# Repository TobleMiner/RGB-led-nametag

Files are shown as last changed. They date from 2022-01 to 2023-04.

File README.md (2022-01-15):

RGB LED nametag
===============

While there are a few commercially available LED nametags out there they
are usually either monochrome only or far too big and bulky to wear.  
This project aims at designing a device solving that problem.  
At only 84mm wide and 29mm tall it is hardly any larger than normal,
boring paper nametags and packs a whole lot more features:

- WLAN enabled
- 48x16 glorious RGB led pixels with more than 16 million colors each
- Powerful ARM Cortex M7 and Xtensa 32bit dual core
- 3MB of onboard data storage

Nyan cat animation playing on the nametag

# Principle of operation

The RGB LEDs on this nametag are common anode LEDs. The LEDs are divided
into groups of 16 columns each. The display is then multiplexed over those
16 columns, always driving one of the 16 columns in each of the three
groups simultaneously. Each of the 3 groups features 48 low side row
drivers driving the R, G and B emitter of all 16 LEDs in the currently
selected column.  
Both the low and high side drivers are designed as shift registers. The
low side drivers are fed with data from a regular SPI while the high side
drivers are connected to a QSPI interface. On the QSPI interface three
of the four data lines are utilized to provide data for all three LED
groups simultaneously.  
Both the SPI and QSPI are peripherals of an STM32F722 MCU. The STM32
takes care of LED multiplexing, power management, user io and USB.  
To provide WLAN connectivity an ESP32 is connected to the STM32 via
an IRQ line, a SPI interface, an I2C interface and a UART. IO0 and EN of
the ESP32 are also connected to the STM32. This allows the STM32 to be
used as a USB to UART bridge allowing normal programming of the ESP32
directly from your favourite IDE.

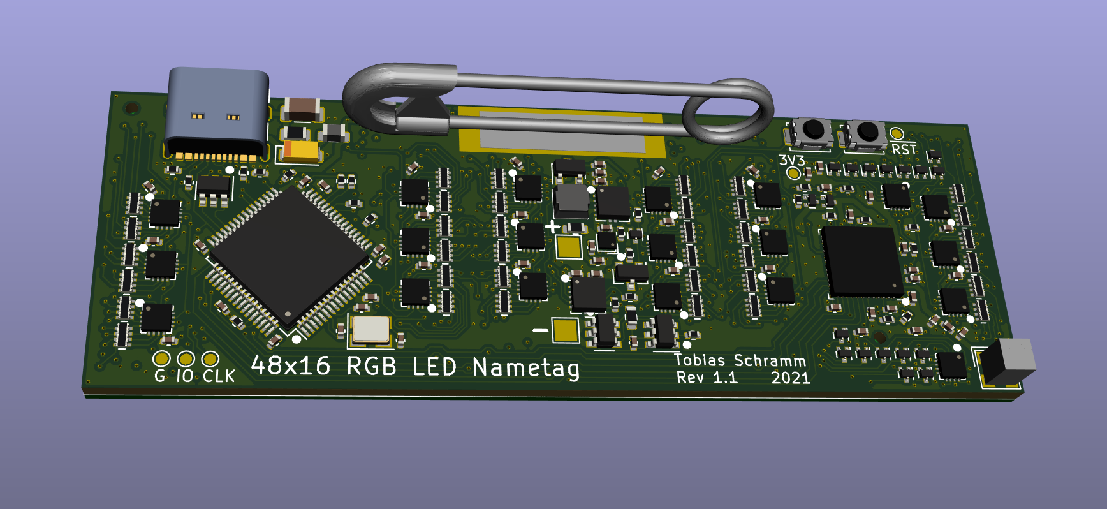
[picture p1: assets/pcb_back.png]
Render of PCB backside


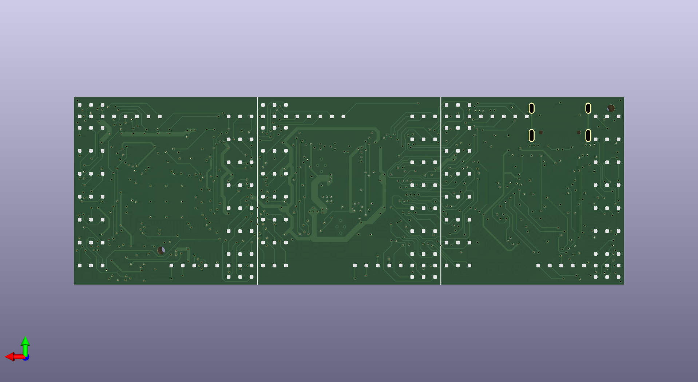
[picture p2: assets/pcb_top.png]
Render of PCB top


# Assembly

Since double sided assembly and boards with blind vias tends to be on the
expensive side this project is comprised of four boards. The first one is
the board shown above. The remaining three boards are all the same and
carry 16x16 LEDs each. They need to be soldered back to back onto the
mainboard. Design files for the LED carrier boards can be found
[here](https://github.com/TobleMiner/16x16-RGB-led-panel).

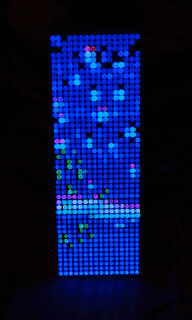
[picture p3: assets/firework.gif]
Firework animation playing on the nametag


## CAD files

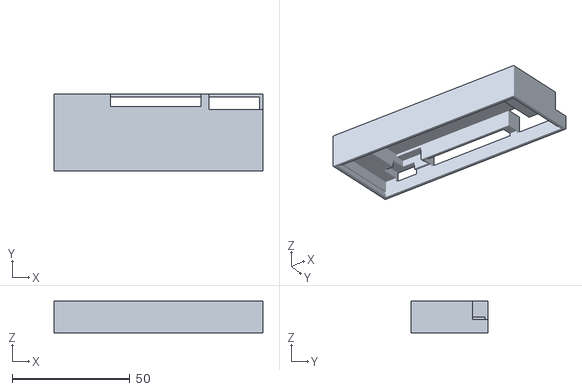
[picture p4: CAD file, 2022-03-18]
3dprinting/led-nametag-case.stl
88.8 x 32.8 x 13.4

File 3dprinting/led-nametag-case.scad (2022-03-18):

/*
Changelog:
  rev1:
    - Increase PCB width from 84 to 85mm
    - Increase PCB height from 27.75 to 29mm
    - Increase play from 0.1 to 0.2mm
    - Move USB port from 5.1 to 5.0mm on the x axis
    - Increase USB port width from 9 to 10mm
    - Increase antenna size from 4.5 to 6mm
    - Increse width of front glas panel from 85 to 86mm
    - Move safety pin from 23mm on the x axis to 22mm
    - Increase width of safety pin from 37.5 to 38.5mm
  rev2:
    - Move battery from 11.5 to 10.5mm
    - Increase battery width from 61 to 63mm
    - Increase battery height from 20 to 21mm
    - Increase USB port thickness from 3.4 to 3.9mm
    - Increase USB port height from 7.5 to 8.5mm
    - Move USB port on y axis from 6 to 7mm
    - Increase PCB height from 29 to 29.25mm
    - Increase height of safety pin from 4 to 5mm
  rev3:
    - Increase PCB height from 29.25 to 30.00mm
    - Decrease height of safety pin from 5 to 4mm
    - Add XTAL bodge cutout
    - Increase battery width from 63 to 65mm
    - Move battery from 10.5 to 9.5mm
  rev4:
    - Increase PCB width from 85 to 86mm
    - Increse width of front glas panel from 86 to 87mm
    - Increse thickness of front glas panel from 1 to 1.2mm
    - Move safety pin from 22mm on the x axis to 22.5mm
    - Increase battery cable width from 11.5 to 12mm
    - Increase battery cable height from 3.4 to 4mm
    - Increase battery cable thickness from battery thickness -2mm to batery thickness - 1mm
  rev5:
    - Introduce USB port thickness offset
  rev6:
    - Change USB port y position from 7 to 7.5mm
    - Increase USB port height from 8.5mm to 9mm
*/

PCB_WIDTH = 86;
PCB_HEIGHT = 30;
WALL_THICKNESS = 1.2;
PLAY = 0.2;
PCB_THICKNESS = 3.3;
DEVICE_THICKNESS = 10.65;
BACKING_THICKNESS = 0.4;
GLASS_THICKNESS = 1.2;
GLASS_INSET = 1.2;
GLASS_WIDTH = 87;
COMPONENT_HEIGHT = 1;
TAPE_THICKNESS = 1.1;

// case backside
module case_back() {
    cube([PCB_WIDTH + (WALL_THICKNESS + PLAY) * 2,
      PCB_HEIGHT + (WALL_THICKNESS + PLAY) * 2,
      DEVICE_THICKNESS + BACKING_THICKNESS]);
}

module nametag() {
    USB_PORT_POS_X = 5;
    USB_PORT_POS_Y = 7.5;
    USB_PORT_HEIGHT = 9;
    USB_PORT_WIDTH = 10;
    USB_PORT_THICKNESS = 3.9;
    USB_PORT_THICKNESS_OFFSET = 0.75;
    ANTENNA_WIDTH = 6;
    ANTENNA_HEIGHT = 6;
    ANTENNA_THICKENESS = 6;
    BAT_POS_X = 9.5;
    BAT_POS_Y = 5.3;
    BAT_WIDTH = 65;
    BAT_HEIGHT = 21;
    BAT_THICKNESS = 5.4;
    BAT_CABLE_WIDTH = 12;
    BAT_CABLE_HEIGHT = 4;
    BAT_CABLE_THICKNESS = BAT_THICKNESS - 1;
    XTAL_BODGE_POS_X = 7;
    XTAL_BODGE_WIDTH = 7.5;
    XTAL_BODGE_HEIGHT = 3;
    SAFETY_PIN_POS_X = 22.5;
    SAFETY_IN_POS_Y = 0;
    SAFETY_PIN_WIDTH = 38.5;
    SAFETY_PIN_HEIGHT = 4;
    SAFETY_PIN_THICKNESS = 9.5;
    CONTROLS_POS_X = 21.5;
    CONTROLS_POS_Y = 0;
    CONTROLS_WIDTH = 25;
    CONTROLS_HEIGHT = BAT_POS_Y;
    CONTROLS_THICKNESS = 10;
    cube([PCB_WIDTH, PCB_HEIGHT, PCB_THICKNESS + COMPONENT_HEIGHT + 0.01]);
    translate([USB_PORT_POS_X, PCB_HEIGHT - USB_PORT_POS_Y, PCB_THICKNESS - USB_PORT_THICKNESS_OFFSET]) {
        cube([USB_PORT_WIDTH, USB_PORT_HEIGHT, USB_PORT_THICKNESS + USB_PORT_THICKNESS_OFFSET]);
    }
    translate([BAT_POS_X, PCB_HEIGHT - BAT_POS_Y - BAT_HEIGHT,
                PCB_THICKNESS + COMPONENT_HEIGHT]) {
        cube([BAT_WIDTH, BAT_HEIGHT, BAT_THICKNESS + TAPE_THICKNESS]);
        translate([0, BAT_HEIGHT, 0])
            cube([BAT_CABLE_WIDTH, BAT_CABLE_HEIGHT, BAT_CABLE_THICKNESS + TAPE_THICKNESS]);
        translate([XTAL_BODGE_POS_X, -XTAL_BODGE_HEIGHT, 0])
            cube([XTAL_BODGE_WIDTH, XTAL_BODGE_HEIGHT, BAT_THICKNESS]);
    }
    translate([PCB_WIDTH - ANTENNA_WIDTH, 0, PCB_THICKNESS]) {
        cube([ANTENNA_WIDTH, ANTENNA_HEIGHT, ANTENNA_THICKENESS]);
    }
    translate([SAFETY_PIN_POS_X, PCB_HEIGHT - SAFETY_PIN_HEIGHT, PCB_THICKNESS]) {
        cube([SAFETY_PIN_WIDTH, SAFETY_PIN_HEIGHT + 2, SAFETY_PIN_THICKNESS]);
    }
    translate([PCB_WIDTH - CONTROLS_POS_X, PCB_HEIGHT - CONTROLS_POS_Y - CONTROLS_HEIGHT, PCB_THICKNESS]) {
        cube([CONTROLS_WIDTH + 2, CONTROLS_HEIGHT + 2, CONTROLS_THICKNESS]);
    }
}

module case_front() {
    difference() {
        cube([PCB_WIDTH + (WALL_THICKNESS + PLAY) * 2,
          PCB_HEIGHT + (WALL_THICKNESS + PLAY) * 2,
          GLASS_INSET + GLASS_THICKNESS]);
        translate([WALL_THICKNESS + PLAY, WALL_THICKNESS + PLAY]) {
            cube([PCB_WIDTH, PCB_HEIGHT, GLASS_INSET + GLASS_THICKNESS]);
            translate([-(GLASS_WIDTH - PCB_WIDTH) / 2, 0, GLASS_INSET])
                cube([GLASS_WIDTH, PCB_HEIGHT, GLASS_THICKNESS]);
        }
    }
}

translate([0, 0, -(GLASS_INSET + GLASS_THICKNESS)]) case_front();

difference() {
    case_back();
    translate([(WALL_THICKNESS + PLAY), (WALL_THICKNESS + PLAY), 0 ]) nametag();
}
      

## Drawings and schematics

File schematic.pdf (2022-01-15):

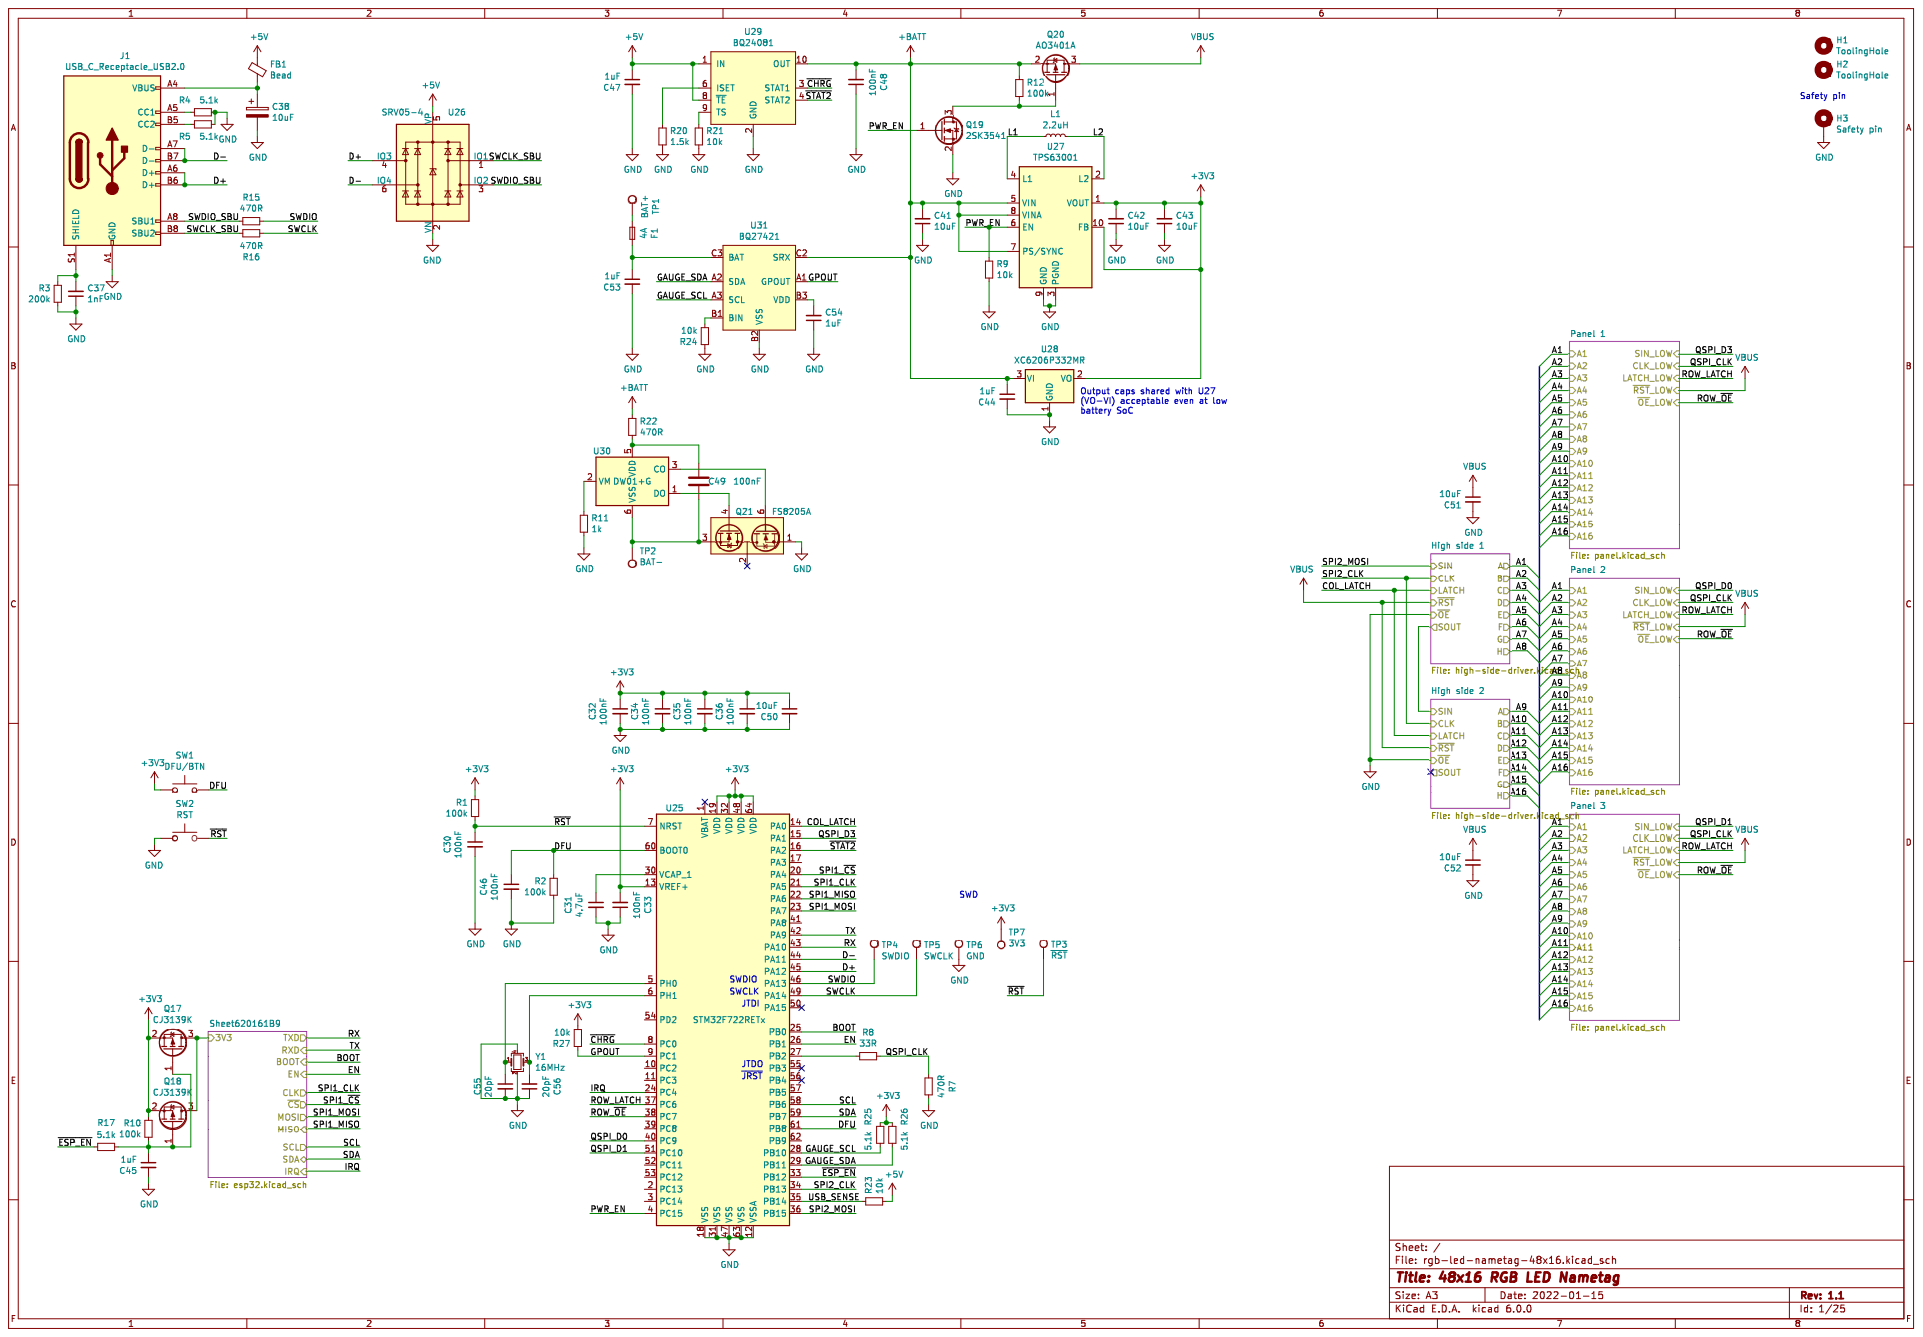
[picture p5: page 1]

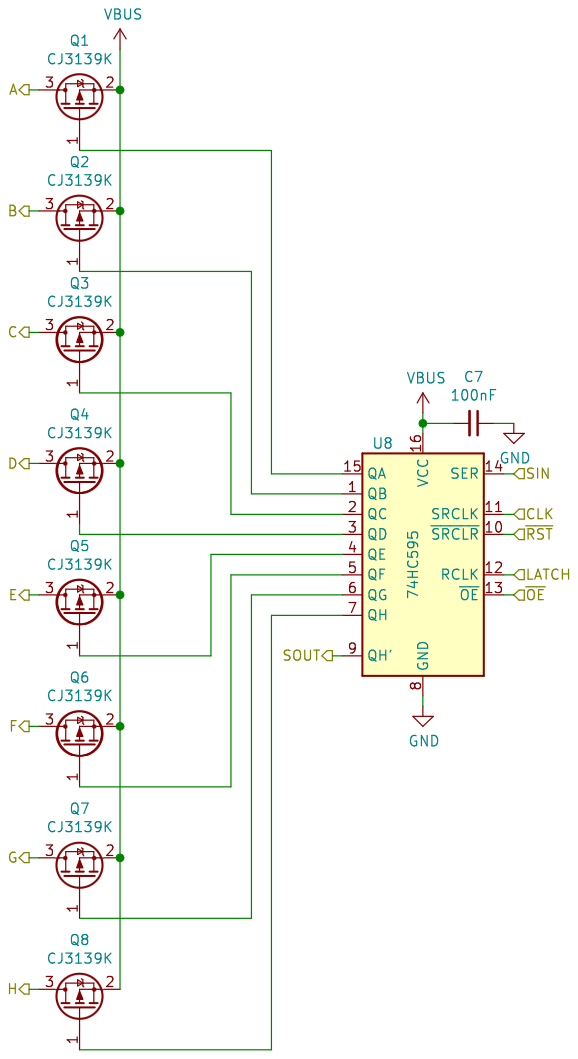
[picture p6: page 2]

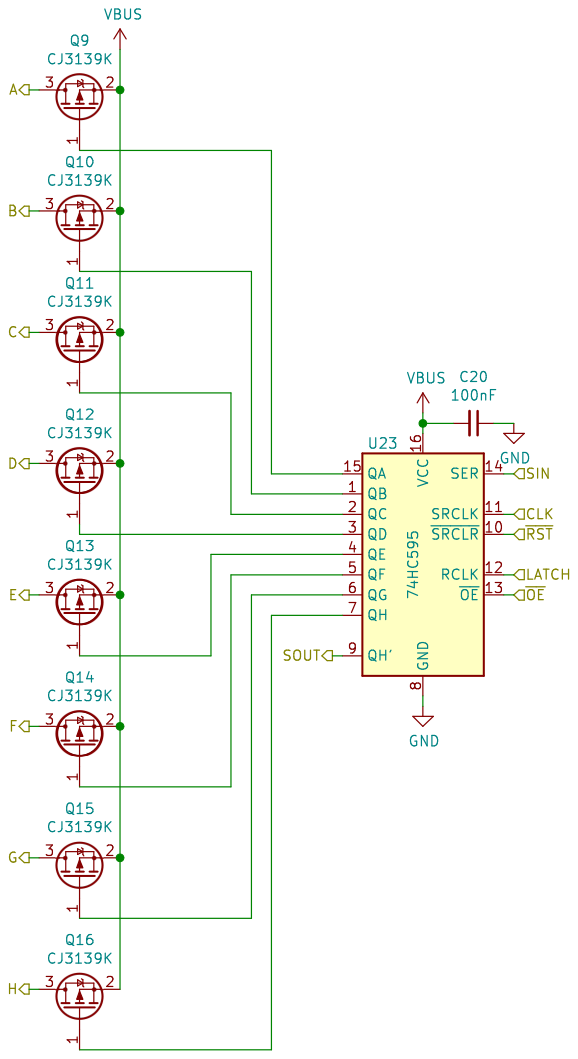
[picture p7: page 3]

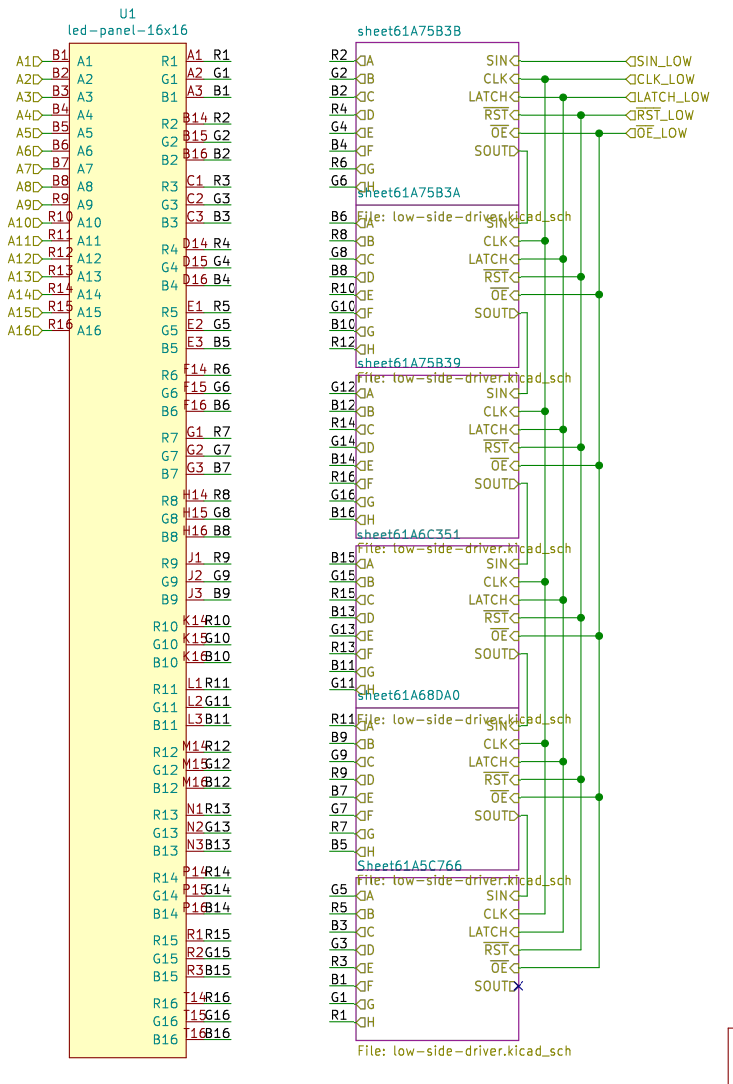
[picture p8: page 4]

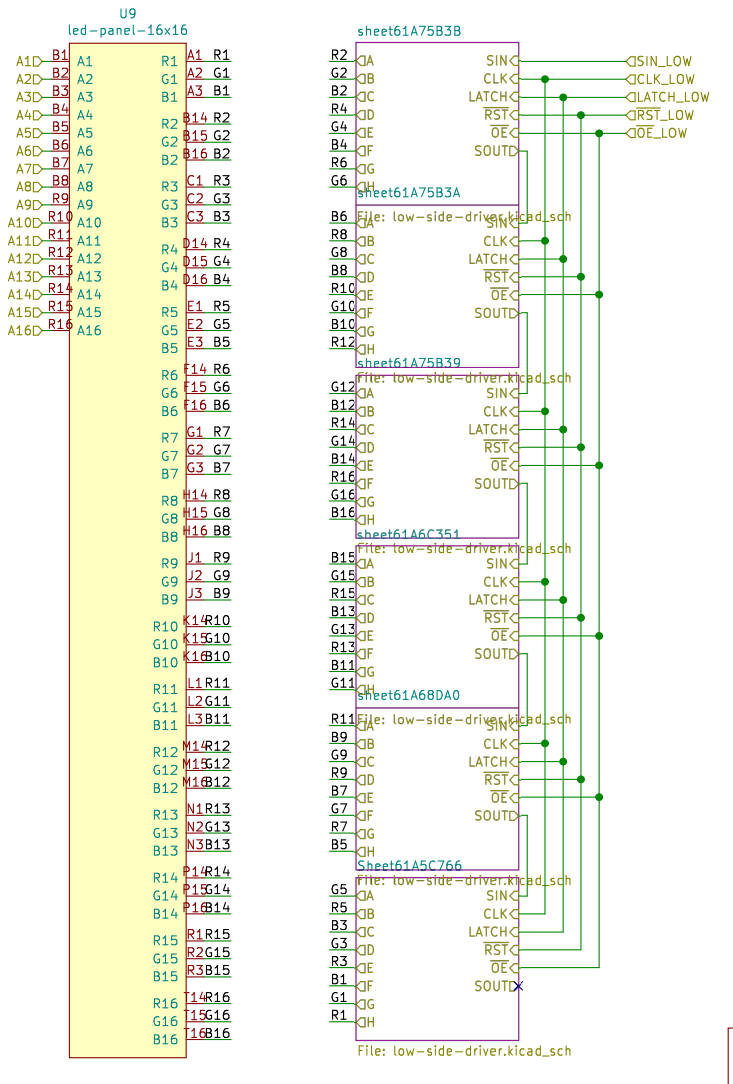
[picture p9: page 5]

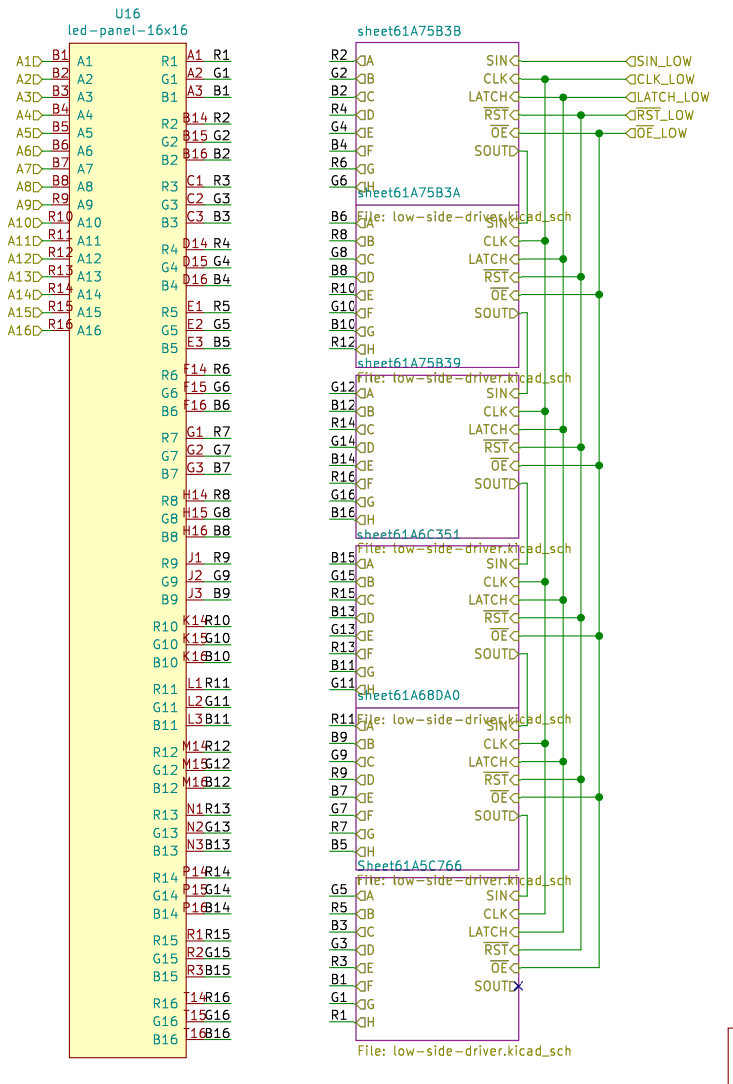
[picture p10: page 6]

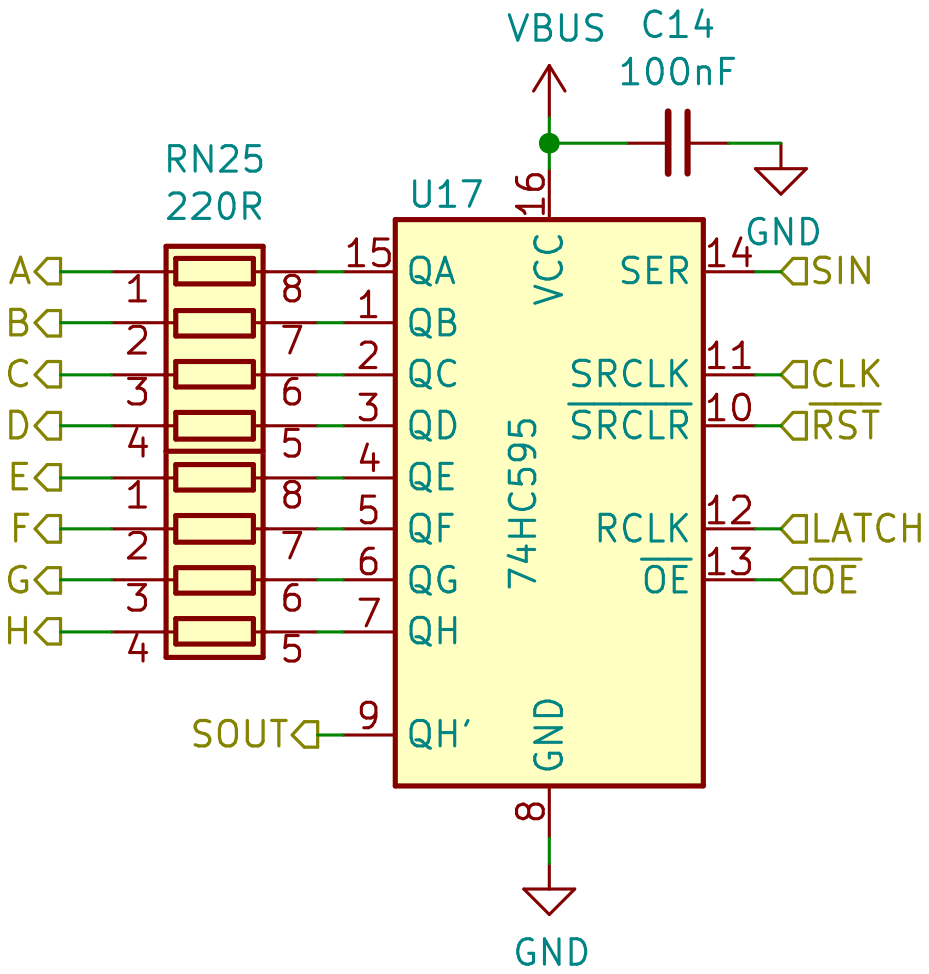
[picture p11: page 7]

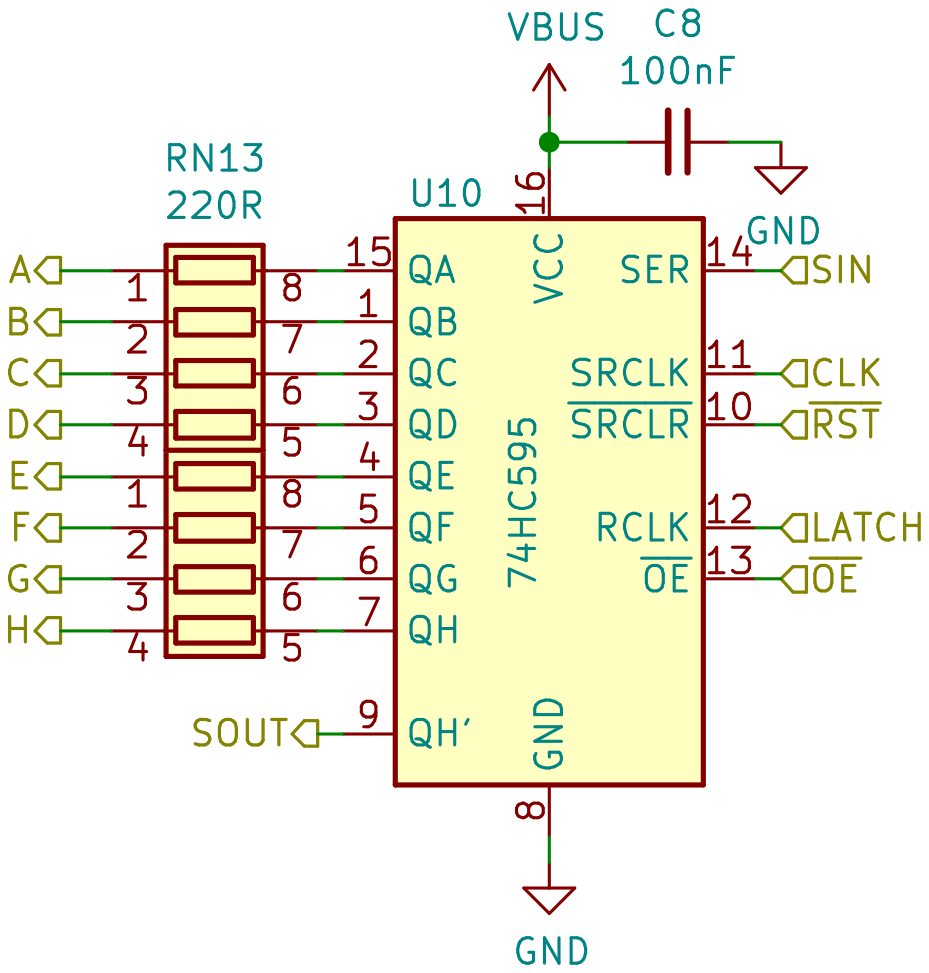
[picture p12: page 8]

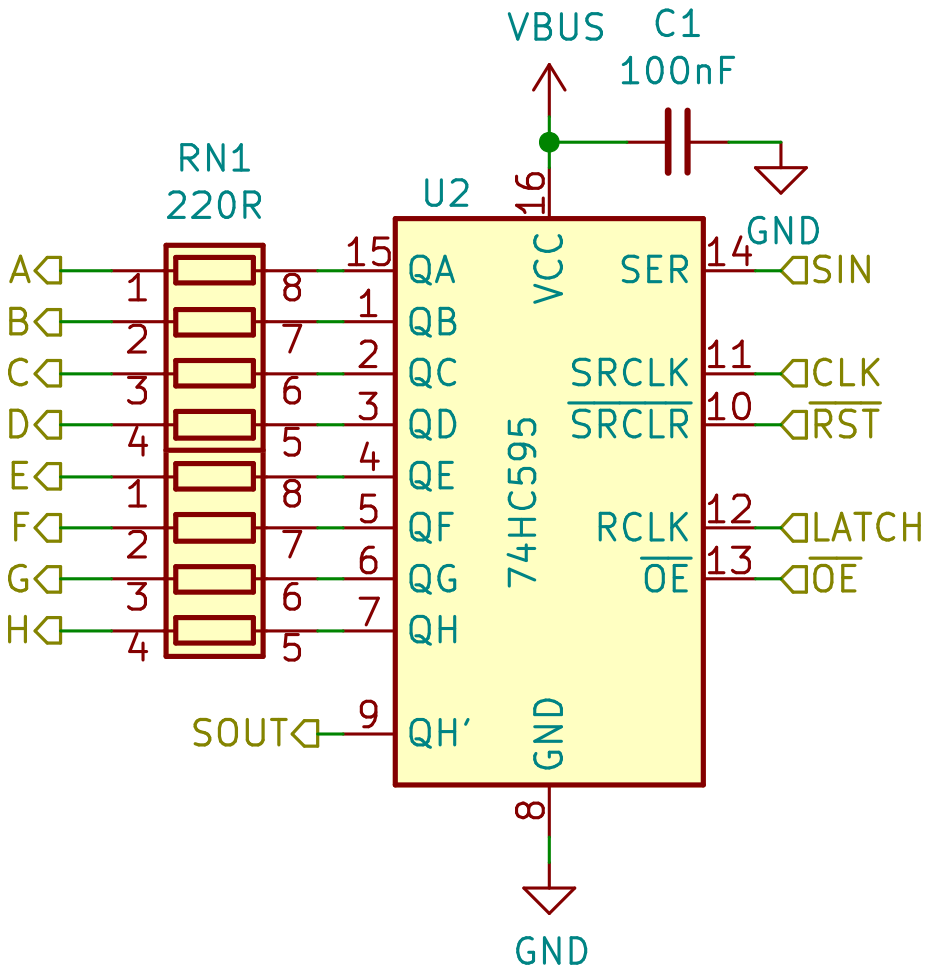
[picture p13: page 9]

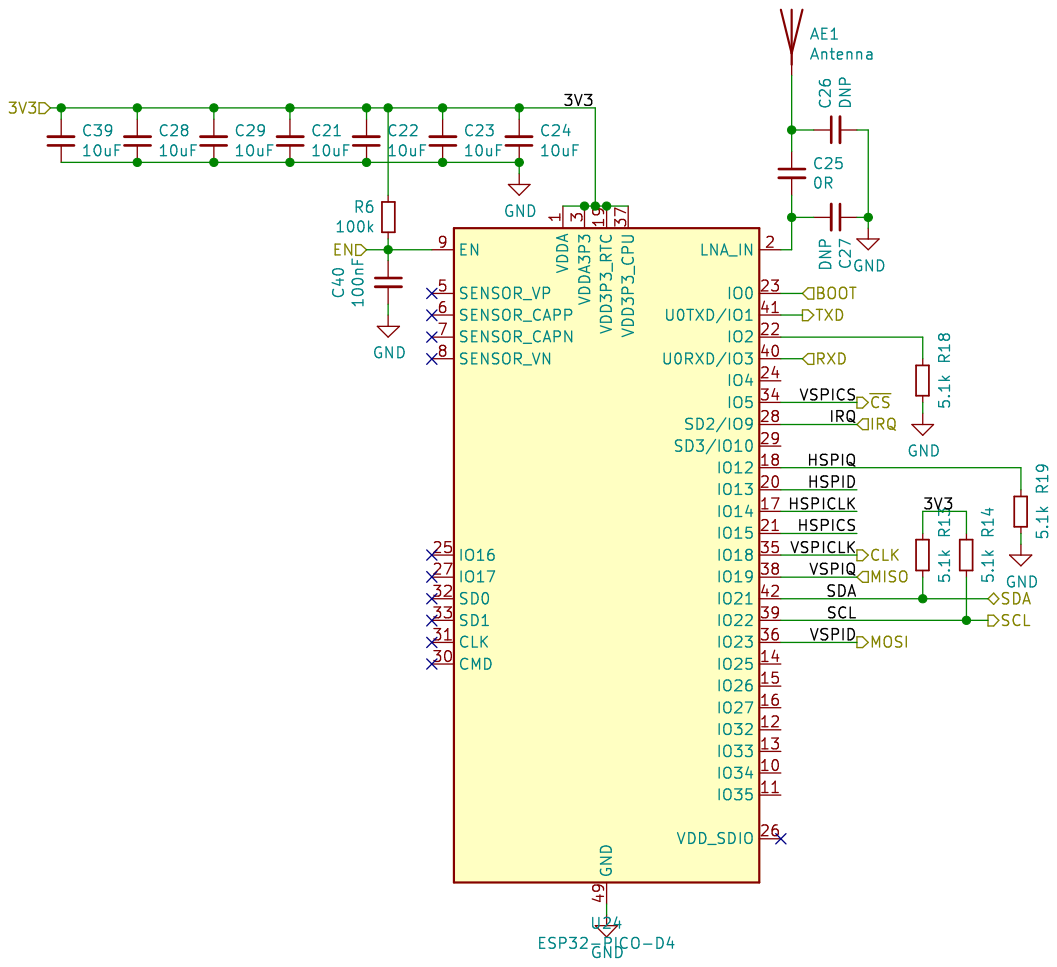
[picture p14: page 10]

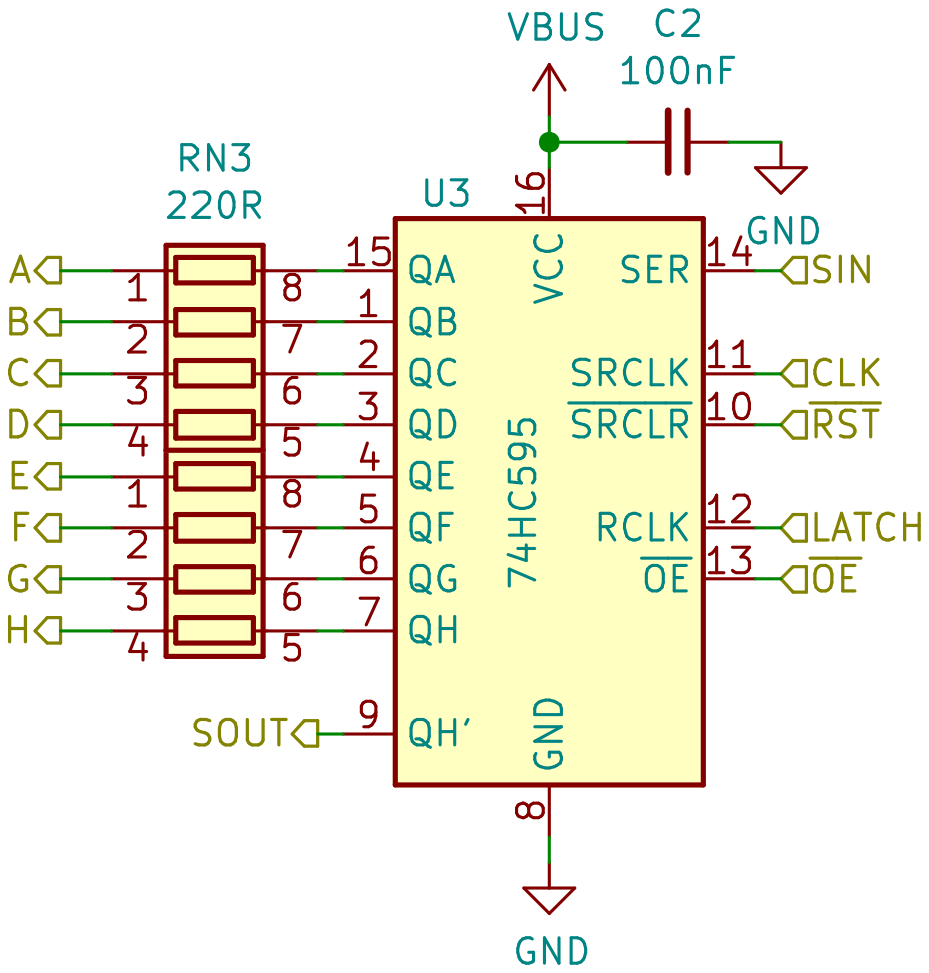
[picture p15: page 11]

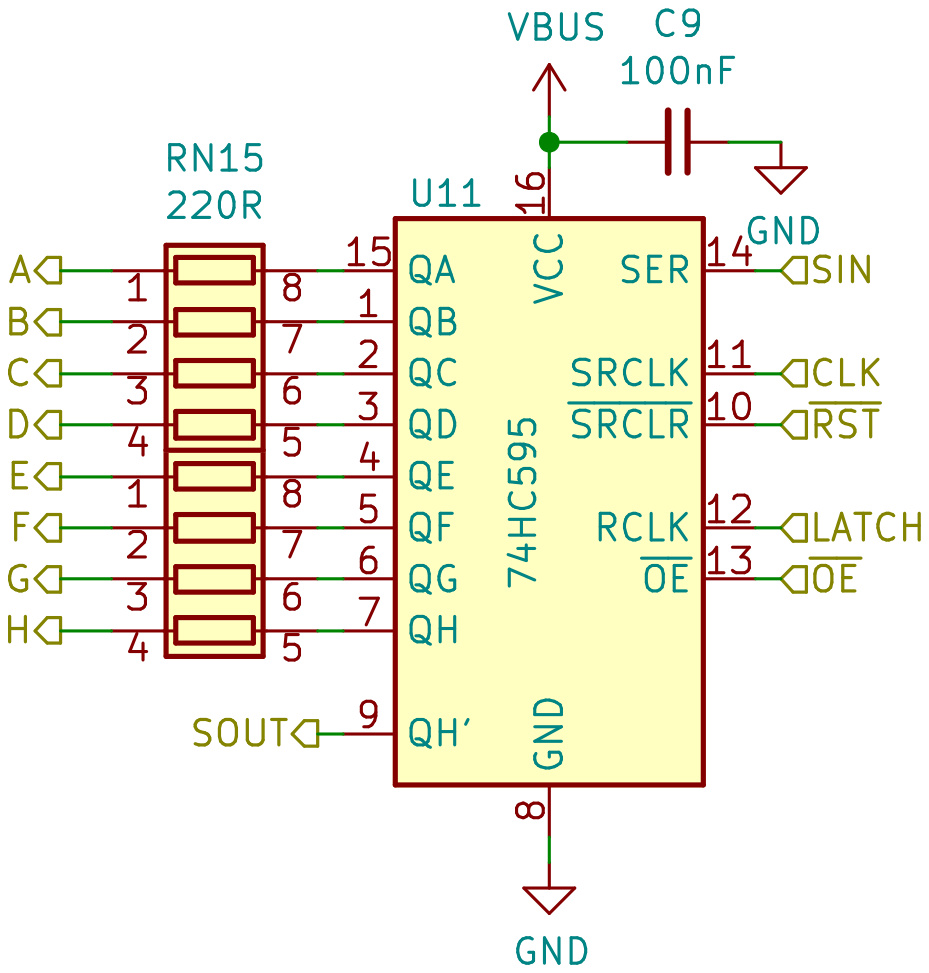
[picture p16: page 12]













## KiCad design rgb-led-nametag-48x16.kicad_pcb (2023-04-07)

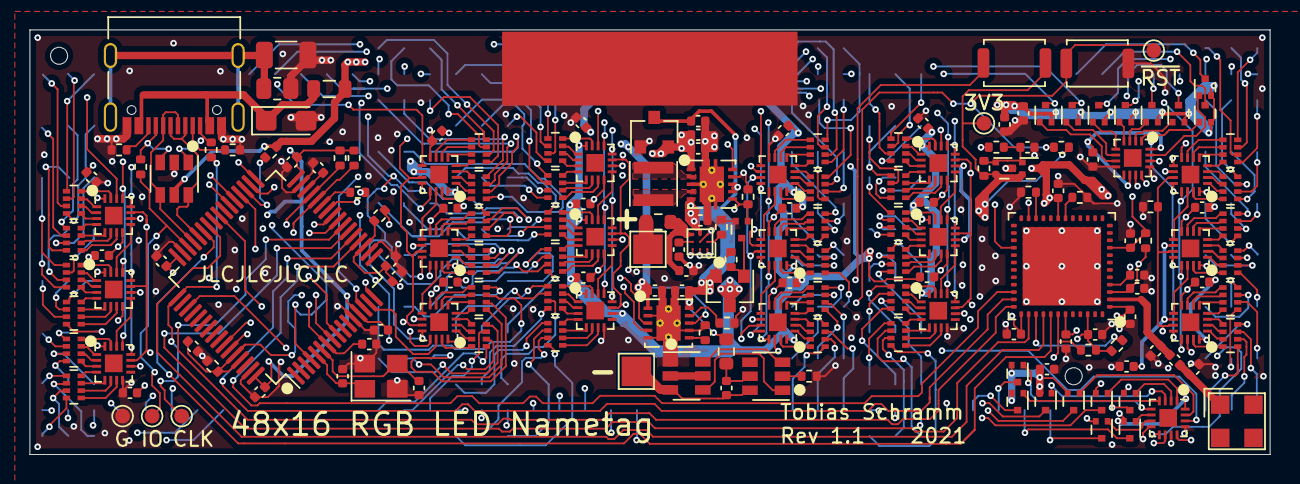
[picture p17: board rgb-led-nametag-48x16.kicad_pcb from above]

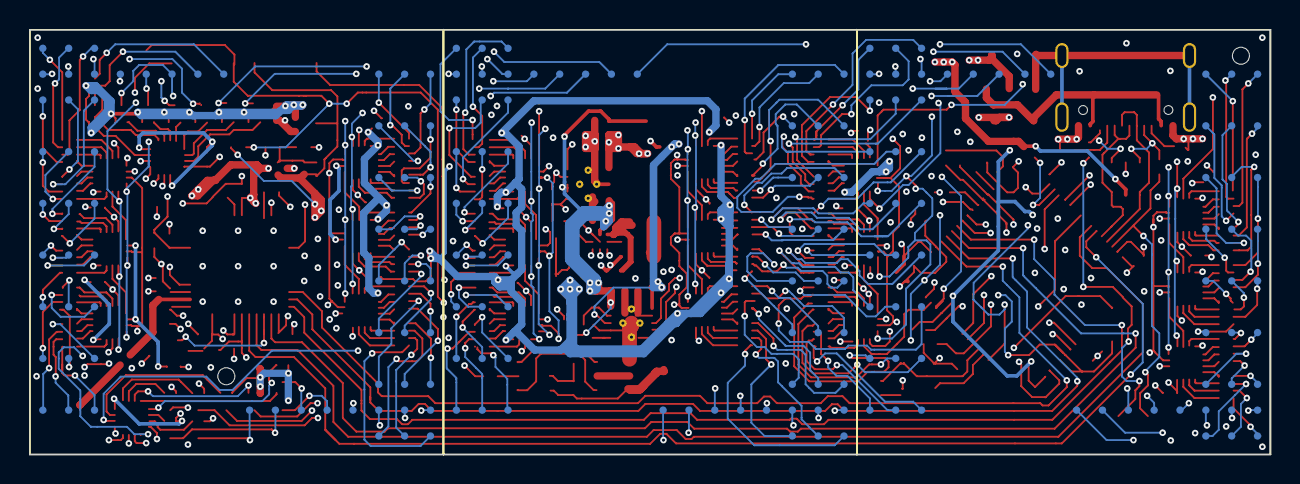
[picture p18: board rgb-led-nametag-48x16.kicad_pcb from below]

Board: 4 copper layers, 84.0 x 28.8 mm, 189 parts (3 on the bottom side), 405 nets.

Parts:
AE1: Antenna; 2065130001
C1, C2, C3, C4, C5, C6, C7, C8, C9, C10, C11, C12, C13, C14, C15, C16, C17, C18, C19, C20, C30, C32, C33, C34, C35, C36, C40, C46, C48, C49: 100nF; C_0402_1005Metric
C21, C22, C23, C24, C28, C29, C39, C41, C42, C43, C50, C51, C52: 10uF; C_0402_1005Metric
C25: 0R; C_0402_1005Metric
C26, C27: DNP; C_0402_1005Metric
C31: 4.7uF; C_0402_1005Metric
C37: 1nF; C_1206_3216Metric
C38: 10uF; CP_EIA-3216-10_Kemet-I
C44, C45, C47, C53, C54: 1uF; C_0402_1005Metric
C55, C56: 20pF; C_0402_1005Metric
F1: 4A; R_0603_1608Metric
FB1: Bead; L_0805_2012Metric
H1, H2: ToolingHole; ToolingHole_JLCSMT
H3: Safety pin; MountingPad_20x5mm
J1: USB_C_Receptacle_USB2.0; USB_C_Receptacle_Palconn_UTC16-G
L1: 2.2uH; L_Taiyo-Yuden_MD-3030
Q1, Q2, Q3, Q4, Q5, Q6, Q7, Q8, Q9, Q10, Q11, Q12, Q13, Q14, Q15, Q16, Q17, Q18: CJ3139K; SOT-723
Q19: 2SK3541; SOT-723
Q20: AO3401A; SOT-23
Q21: FS8205A; SOT-23-6
R1, R2, R6, R10, R12: 100k; R_0402_1005Metric
R3: 200k; R_0805_2012Metric
R4, R5, R13, R14, R17, R18, R19, R25, R26: 5.1k; R_0402_1005Metric
R7, R15, R16: 470R; R_0402_1005Metric
R8: 33R; R_0402_1005Metric
R9, R21, R23, R24, R27: 10k; R_0402_1005Metric
R11: 1k; R_0402_1005Metric
R20: 1.5k; R_0402_1005Metric
R22: 470R; R_0603_1608Metric
RN1, RN2, RN3, RN4, RN5, RN6, RN7, RN8, RN9, RN10, RN11, RN12, RN13, RN14, RN15, RN16, RN17, RN18, RN19, RN20, RN21, RN22, RN23, RN24, RN25, RN26, RN27, RN28, RN29, RN30, RN31, RN32, RN33, RN34, RN35, RN36: 220R; R_Array_Concave_4x0402
SW1: DFU/BTN; SW_Push_SPST_NO_Alps_SKRK
SW2: RST; SW_Push_SPST_NO_Alps_SKRK
TP1: BAT+; TestPoint_Pad_2.0x2.0mm
TP2: BAT-; TestPoint_Pad_2.0x2.0mm
TP3: ~{RST}; TestPoint_Pad_D1.0mm
TP4: SWDIO; TestPoint_Pad_D1.0mm
TP5: SWCLK; TestPoint_Pad_D1.0mm
TP6: GND; TestPoint_Pad_D1.0mm
TP7: 3V3; TestPoint_Pad_D1.0mm
U1, U9, U16: led-panel-16x16; bga-led-panel-16x16
U2, U3, U4, U5, U6, U7, U8, U10, U11, U12, U13, U14, U15, U17, U18, U19, U20, U21, U22, U23: 74HC595; X1QFN-16-2.5x2.5-EP-1.2
U24: ESP32-PICO-D4; ESP32-Pico-D4
U25: STM32F722RETx; LQFP-64_10x10mm_P0.5mm
U26: SRV05-4; SOT-23-6
U27: TPS63001; Texas_DRC0010J_ThermalVias
U28: XC6206P332MR; SOT-23
U29: BQ24081; Texas_DRC0010J_ThermalVias
U30: DW01+G; SOT-23-6
U31: BQ27421; DSBGA-9_1.6x1.6_P0.5mm
Y1: 16MHz; Crystal_SMD_3225-4Pin_3.2x2.5mm

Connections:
+3V3: C32.1, C33.2, C34.1, C35.1, C36.1, C42.2, C43.2, C50.1, Q17.2 (S), Q18.2 (S), R1.2, R10.2, R25.2, R26.1, R27.2, SW1.2, TP7.1, U25.13 (VREF+), U25.19 (VDD), U25.32 (VDD), U25.48 (VDD), U25.64 (VDD), U27.1 (VOUT), U27.10 (FB), U28.2 (VO)
+5V: C47.1, FB1.1, R23.2, U26.5 (VP), U29.1 (IN), U29.8 (~TE)
+BATT: C41.2, C44.1, C48.2, Q20.2 (S), R12.1, R22.1, U27.5 (VIN), U27.7 (PS/SYNC), U27.8 (VINA), U28.3 (VI), U29.10 (OUT), U31.C2 (SRX)
/A1: Q1.3 (D), U1.B1 (A1), U9.B1 (A1), U16.B1 (A1)
/A2: Q2.3 (D), U1.B2 (A2), U9.B2 (A2), U16.B2 (A2)
/A3: Q3.3 (D), U1.B3 (A3), U9.B3 (A3), U16.B3 (A3)
/A4: Q4.3 (D), U1.B4 (A4), U9.B4 (A4), U16.B4 (A4)
/A5: Q5.3 (D), U1.B5 (A5), U9.B5 (A5), U16.B5 (A5)
/A6: Q6.3 (D), U1.B6 (A6), U9.B6 (A6), U16.B6 (A6)
/A7: Q7.3 (D), U1.B7 (A7), U9.B7 (A7), U16.B7 (A7)
/A8: Q8.3 (D), U1.B8 (A8), U9.B8 (A8), U16.B8 (A8)
/A9: Q9.3 (D), U1.R9 (A9), U9.R9 (A9), U16.R9 (A9)
/A10: Q10.3 (D), U1.R10 (A10), U9.R10 (A10), U16.R10 (A10)
/A11: Q11.3 (D), U1.R11 (A11), U9.R11 (A11), U16.R11 (A11)
/A12: Q12.3 (D), U1.R12 (A12), U9.R12 (A12), U16.R12 (A12)
/A13: Q13.3 (D), U1.R13 (A13), U9.R13 (A13), U16.R13 (A13)
/A14: Q14.3 (D), U1.R14 (A14), U9.R14 (A14), U16.R14 (A14)
/A15: Q15.3 (D), U1.R15 (A15), U9.R15 (A15), U16.R15 (A15)
/A16: Q16.3 (D), U1.R16 (A16), U9.R16 (A16), U16.R16 (A16)
/BOOT: U24.23 (IO0), U25.25 (PB0)
/COL_LATCH: U8.12 (RCLK), U23.12 (RCLK), U25.14 (PA0)
/D+: J1.A6 (D+), J1.B6 (D+), U25.45 (PA12), U26.4 (IO3)
/D-: J1.A7 (D-), J1.B7 (D-), U25.44 (PA11), U26.6 (IO4)
/DFU: C46.1, R2.2, SW1.1, U25.60 (BOOT0), U25.61 (PB8)
/EN: C40.1, R6.1, U24.9 (EN), U25.26 (PB1)
/GAUGE_SCL: R25.1, U25.28 (PB10), U31.A3 (SCL)
/GAUGE_SDA: R26.2, U25.29 (PB11), U31.A2 (SDA)
/GPOUT: R27.1, U25.9 (PC1), U31.A1 (GPOUT)
/High side 1/SOUT: U8.9 (QH'), U23.14 (SER)
/IRQ: U24.28 (SD2/IO9), U25.24 (PC4)
/L1: L1.1, U27.4 (L1)
/L2: L1.2, U27.2 (L2)
/PWR_EN: Q19.1 (G), R9.1, U25.4 (PC15), U27.6 (EN)
/Panel 1/B1: RN2.2 (R2.1), U1.A3 (B1)
/Panel 1/B2: RN11.3 (R3.1), U1.B16 (B2)
/Panel 1/B3: RN1.3 (R3.1), U1.C3 (B3)
/Panel 1/B4: RN12.2 (R2.1), U1.D16 (B4)
/Panel 1/B5: RN4.4 (R4.1), U1.E3 (B5)
/Panel 1/B6: RN9.1 (R1.1), U1.F16 (B6)
/Panel 1/B7: RN4.1 (R1.1), U1.G3 (B7)
/Panel 1/B8: RN9.4 (R4.1), U1.H16 (B8)
/Panel 1/B9: RN3.2 (R2.1), U1.J3 (B9)
/Panel 1/B10: RN10.3 (R3.1), U1.K16 (B10)
/Panel 1/B11: RN6.3 (R3.1), U1.L3 (B11)
/Panel 1/B12: RN7.2 (R2.1), U1.M16 (B12)
/Panel 1/B13: RN5.4 (R4.1), U1.N3 (B13)
/Panel 1/B14: RN8.1 (R1.1), U1.P16 (B14)
/Panel 1/B15: RN5.1 (R1.1), U1.R3 (B15)
/Panel 1/B16: RN8.4 (R4.1), U1.T16 (B16)
/Panel 1/G1: RN2.3 (R3.1), U1.A2 (G1)
/Panel 1/G2: RN11.2 (R2.1), U1.B15 (G2)
/Panel 1/G3: RN1.4 (R4.1), U1.C2 (G3)
/Panel 1/G4: RN12.1 (R1.1), U1.D15 (G4)
/Panel 1/G5: RN1.1 (R1.1), U1.E2 (G5)
/Panel 1/G6: RN12.4 (R4.1), U1.F15 (G6)
/Panel 1/G7: RN4.2 (R2.1), U1.G2 (G7)
/Panel 1/G8: RN9.3 (R3.1), U1.H15 (G8)
/Panel 1/G9: RN3.3 (R3.1), U1.J2 (G9)
/Panel 1/G10: RN10.2 (R2.1), U1.K15 (G10)
/Panel 1/G11: RN6.4 (R4.1), U1.L2 (G11)
/Panel 1/G12: RN7.1 (R1.1), U1.M15 (G12)
/Panel 1/G13: RN6.1 (R1.1), U1.N2 (G13)
/Panel 1/G14: RN7.4 (R4.1), U1.P15 (G14)
/Panel 1/G15: RN5.2 (R2.1), U1.R2 (G15)
/Panel 1/G16: RN8.3 (R3.1), U1.T15 (G16)
/Panel 1/R1: RN2.4 (R4.1), U1.A1 (R1)
/Panel 1/R2: RN11.1 (R1.1), U1.B14 (R2)
/Panel 1/R3: RN2.1 (R1.1), U1.C1 (R3)
/Panel 1/R4: RN11.4 (R4.1), U1.D14 (R4)
/Panel 1/R5: RN1.2 (R2.1), U1.E1 (R5)
/Panel 1/R6: RN12.3 (R3.1), U1.F14 (R6)
/Panel 1/R7: RN4.3 (R3.1), U1.G1 (R7)
/Panel 1/R8: RN9.2 (R2.1), U1.H14 (R8)
/Panel 1/R9: RN3.4 (R4.1), U1.J1 (R9)
/Panel 1/R10: RN10.1 (R1.1), U1.K14 (R10)
/Panel 1/R11: RN3.1 (R1.1), U1.L1 (R11)
/Panel 1/R12: RN10.4 (R4.1), U1.M14 (R12)
/Panel 1/R13: RN6.2 (R2.1), U1.N1 (R13)
/Panel 1/R14: RN7.3 (R3.1), U1.P14 (R14)
/Panel 1/R15: RN5.3 (R3.1), U1.R1 (R15)
/Panel 1/R16: RN8.2 (R2.1), U1.T14 (R16)
/Panel 1/Sheet61A5C766/SIN: U2.14 (SER), U3.9 (QH')
/Panel 1/sheet61A6C351/SIN: U4.14 (SER), U5.9 (QH')
/Panel 1/sheet61A68DA0/SIN: U3.14 (SER), U4.9 (QH')
/Panel 1/sheet61A75B3A/SIN: U6.14 (SER), U7.9 (QH')
/Panel 1/sheet61A75B39/SIN: U5.14 (SER), U6.9 (QH')
/Panel 2/B1: RN14.2 (R2.1), U9.A3 (B1)
/Panel 2/B2: RN23.3 (R3.1), U9.B16 (B2)
/Panel 2/B3: RN13.3 (R3.1), U9.C3 (B3)
/Panel 2/B4: RN24.2 (R2.1), U9.D16 (B4)
/Panel 2/B5: RN16.4 (R4.1), U9.E3 (B5)
/Panel 2/B6: RN21.1 (R1.1), U9.F16 (B6)
/Panel 2/B7: RN16.1 (R1.1), U9.G3 (B7)
/Panel 2/B8: RN21.4 (R4.1), U9.H16 (B8)
/Panel 2/B9: RN15.2 (R2.1), U9.J3 (B9)
/Panel 2/B10: RN22.3 (R3.1), U9.K16 (B10)
/Panel 2/B11: RN18.3 (R3.1), U9.L3 (B11)
/Panel 2/B12: RN19.2 (R2.1), U9.M16 (B12)
/Panel 2/B13: RN17.4 (R4.1), U9.N3 (B13)
/Panel 2/B14: RN20.1 (R1.1), U9.P16 (B14)
/Panel 2/B15: RN17.1 (R1.1), U9.R3 (B15)
/Panel 2/B16: RN20.4 (R4.1), U9.T16 (B16)
/Panel 2/G1: RN14.3 (R3.1), U9.A2 (G1)
/Panel 2/G2: RN23.2 (R2.1), U9.B15 (G2)
/Panel 2/G3: RN13.4 (R4.1), U9.C2 (G3)
/Panel 2/G4: RN24.1 (R1.1), U9.D15 (G4)
/Panel 2/G5: RN13.1 (R1.1), U9.E2 (G5)
/Panel 2/G6: RN24.4 (R4.1), U9.F15 (G6)
/Panel 2/G7: RN16.2 (R2.1), U9.G2 (G7)
/Panel 2/G8: RN21.3 (R3.1), U9.H15 (G8)
/Panel 2/G9: RN15.3 (R3.1), U9.J2 (G9)
/Panel 2/G10: RN22.2 (R2.1), U9.K15 (G10)
/Panel 2/G11: RN18.4 (R4.1), U9.L2 (G11)
/Panel 2/G12: RN19.1 (R1.1), U9.M15 (G12)
/Panel 2/G13: RN18.1 (R1.1), U9.N2 (G13)
/Panel 2/G14: RN19.4 (R4.1), U9.P15 (G14)
/Panel 2/G15: RN17.2 (R2.1), U9.R2 (G15)
/Panel 2/G16: RN20.3 (R3.1), U9.T15 (G16)
/Panel 2/R1: RN14.4 (R4.1), U9.A1 (R1)
/Panel 2/R2: RN23.1 (R1.1), U9.B14 (R2)
/Panel 2/R3: RN14.1 (R1.1), U9.C1 (R3)
/Panel 2/R4: RN23.4 (R4.1), U9.D14 (R4)
/Panel 2/R5: RN13.2 (R2.1), U9.E1 (R5)
/Panel 2/R6: RN24.3 (R3.1), U9.F14 (R6)
/Panel 2/R7: RN16.3 (R3.1), U9.G1 (R7)
/Panel 2/R8: RN21.2 (R2.1), U9.H14 (R8)
/Panel 2/R9: RN15.4 (R4.1), U9.J1 (R9)
/Panel 2/R10: RN22.1 (R1.1), U9.K14 (R10)
/Panel 2/R11: RN15.1 (R1.1), U9.L1 (R11)
/Panel 2/R12: RN22.4 (R4.1), U9.M14 (R12)
/Panel 2/R13: RN18.2 (R2.1), U9.N1 (R13)
/Panel 2/R14: RN19.3 (R3.1), U9.P14 (R14)
/Panel 2/R15: RN17.3 (R3.1), U9.R1 (R15)
/Panel 2/R16: RN20.2 (R2.1), U9.T14 (R16)
/Panel 2/Sheet61A5C766/SIN: U10.14 (SER), U11.9 (QH')
/Panel 2/sheet61A6C351/SIN: U12.14 (SER), U13.9 (QH')
/Panel 2/sheet61A68DA0/SIN: U11.14 (SER), U12.9 (QH')
/Panel 2/sheet61A75B3A/SIN: U14.14 (SER), U15.9 (QH')
/Panel 2/sheet61A75B39/SIN: U13.14 (SER), U14.9 (QH')
/Panel 3/B1: RN26.2 (R2.1), U16.A3 (B1)
/Panel 3/B2: RN35.3 (R3.1), U16.B16 (B2)
/Panel 3/B3: RN25.3 (R3.1), U16.C3 (B3)
/Panel 3/B4: RN36.2 (R2.1), U16.D16 (B4)
/Panel 3/B5: RN28.4 (R4.1), U16.E3 (B5)
/Panel 3/B6: RN33.1 (R1.1), U16.F16 (B6)
/Panel 3/B7: RN28.1 (R1.1), U16.G3 (B7)
/Panel 3/B8: RN33.4 (R4.1), U16.H16 (B8)
/Panel 3/B9: RN27.2 (R2.1), U16.J3 (B9)
/Panel 3/B10: RN34.3 (R3.1), U16.K16 (B10)
/Panel 3/B11: RN30.3 (R3.1), U16.L3 (B11)
/Panel 3/B12: RN31.2 (R2.1), U16.M16 (B12)
/Panel 3/B13: RN29.4 (R4.1), U16.N3 (B13)
/Panel 3/B14: RN32.1 (R1.1), U16.P16 (B14)
/Panel 3/B15: RN29.1 (R1.1), U16.R3 (B15)
/Panel 3/B16: RN32.4 (R4.1), U16.T16 (B16)
/Panel 3/G1: RN26.3 (R3.1), U16.A2 (G1)
/Panel 3/G2: RN35.2 (R2.1), U16.B15 (G2)
/Panel 3/G3: RN25.4 (R4.1), U16.C2 (G3)
/Panel 3/G4: RN36.1 (R1.1), U16.D15 (G4)
/Panel 3/G5: RN25.1 (R1.1), U16.E2 (G5)
/Panel 3/G6: RN36.4 (R4.1), U16.F15 (G6)
/Panel 3/G7: RN28.2 (R2.1), U16.G2 (G7)
/Panel 3/G8: RN33.3 (R3.1), U16.H15 (G8)
/Panel 3/G9: RN27.3 (R3.1), U16.J2 (G9)
/Panel 3/G10: RN34.2 (R2.1), U16.K15 (G10)
/Panel 3/G11: RN30.4 (R4.1), U16.L2 (G11)
/Panel 3/G12: RN31.1 (R1.1), U16.M15 (G12)
/Panel 3/G13: RN30.1 (R1.1), U16.N2 (G13)
/Panel 3/G14: RN31.4 (R4.1), U16.P15 (G14)
/Panel 3/G15: RN29.2 (R2.1), U16.R2 (G15)
/Panel 3/G16: RN32.3 (R3.1), U16.T15 (G16)
/Panel 3/R1: RN26.4 (R4.1), U16.A1 (R1)
/Panel 3/R2: RN35.1 (R1.1), U16.B14 (R2)
/Panel 3/R3: RN26.1 (R1.1), U16.C1 (R3)
/Panel 3/R4: RN35.4 (R4.1), U16.D14 (R4)
/Panel 3/R5: RN25.2 (R2.1), U16.E1 (R5)
/Panel 3/R6: RN36.3 (R3.1), U16.F14 (R6)
/Panel 3/R7: RN28.3 (R3.1), U16.G1 (R7)
/Panel 3/R8: RN33.2 (R2.1), U16.H14 (R8)
/Panel 3/R9: RN27.4 (R4.1), U16.J1 (R9)
/Panel 3/R10: RN34.1 (R1.1), U16.K14 (R10)
/Panel 3/R11: RN27.1 (R1.1), U16.L1 (R11)
/Panel 3/R12: RN34.4 (R4.1), U16.M14 (R12)
/Panel 3/R13: RN30.2 (R2.1), U16.N1 (R13)
/Panel 3/R14: RN31.3 (R3.1), U16.P14 (R14)
/Panel 3/R15: RN29.3 (R3.1), U16.R1 (R15)
/Panel 3/R16: RN32.2 (R2.1), U16.T14 (R16)
/Panel 3/Sheet61A5C766/SIN: U17.14 (SER), U18.9 (QH')
/Panel 3/sheet61A6C351/SIN: U19.14 (SER), U20.9 (QH')
/Panel 3/sheet61A68DA0/SIN: U18.14 (SER), U19.9 (QH')
/Panel 3/sheet61A75B3A/SIN: U21.14 (SER), U22.9 (QH')
/Panel 3/sheet61A75B39/SIN: U20.14 (SER), U21.9 (QH')
/QSPI_CLK: R7.2, R8.1, U2.11 (SRCLK), U3.11 (SRCLK), U4.11 (SRCLK), U5.11 (SRCLK), U6.11 (SRCLK), U7.11 (SRCLK), U10.11 (SRCLK), U11.11 (SRCLK), U12.11 (SRCLK), U13.11 (SRCLK), U14.11 (SRCLK), U15.11 (SRCLK), U17.11 (SRCLK), U18.11 (SRCLK), U19.11 (SRCLK), U20.11 (SRCLK), U21.11 (SRCLK), U22.11 (SRCLK)
/QSPI_D0: U15.14 (SER), U25.40 (PC9)
/QSPI_D1: U22.14 (SER), U25.51 (PC10)
/QSPI_D3: U7.14 (SER), U25.15 (PA1)
/ROW_LATCH: U2.12 (RCLK), U3.12 (RCLK), U4.12 (RCLK), U5.12 (RCLK), U6.12 (RCLK), U7.12 (RCLK), U10.12 (RCLK), U11.12 (RCLK), U12.12 (RCLK), U13.12 (RCLK), U14.12 (RCLK), U15.12 (RCLK), U17.12 (RCLK), U18.12 (RCLK), U19.12 (RCLK), U20.12 (RCLK), U21.12 (RCLK), U22.12 (RCLK), U25.37 (PC6)
/ROW_~OE: U2.13 (~OE), U3.13 (~OE), U4.13 (~OE), U5.13 (~OE), U6.13 (~OE), U7.13 (~OE), U10.13 (~OE), U11.13 (~OE), U12.13 (~OE), U13.13 (~OE), U14.13 (~OE), U15.13 (~OE), U17.13 (~OE), U18.13 (~OE), U19.13 (~OE), U20.13 (~OE), U21.13 (~OE), U22.13 (~OE), U25.38 (PC7)
/RX: U24.41 (U0TXD/IO1), U25.43 (PA10)
/SCL: R14.2, U24.39 (IO22), U25.58 (PB6)
/SDA: R13.2, U24.42 (IO21), U25.59 (PB7)
/SPI1_CLK: U24.35 (IO18), U25.21 (PA5)
/SPI1_MISO: U24.38 (IO19), U25.22 (PA6)
/SPI1_MOSI: U24.36 (IO23), U25.23 (PA7)
/SPI1_~CS: U24.34 (IO5), U25.20 (PA4)
/SPI2_CLK: U8.11 (SRCLK), U23.11 (SRCLK), U25.34 (PB13)
/SPI2_MOSI: U8.14 (SER), U25.36 (PB15)
/SWCLK: R16.2, TP5.1, U25.49 (PA14)
/SWCLK_SBU: J1.B8 (SBU2), R16.1, U26.1 (IO1)
/SWDIO: R15.1, TP4.1, U25.46 (PA13)
/SWDIO_SBU: J1.A8 (SBU1), R15.2, U26.3 (IO2)
/Sheet620161B9/3V3: C21.2, C22.2, C23.2, C24.2, C28.2, C29.2, C39.2, Q17.3 (D), Q18.3 (D), R6.2, R13.1, R14.1, U24.1 (VDDA), U24.3 (VDDA3P3), U24.4 (VDDA3P3), U24.19 (VDD3P3_RTC), U24.37 (VDD3P3_CPU), U24.43 (VDDA), U24.46 (VDDA)
/Sheet620161B9/HSPIQ: R19.1, U24.18 (IO12)
/TX: U24.40 (U0RXD/IO3), U25.42 (PA9)
/USB_SENSE: R23.1, U25.35 (PB14)
/~CHRG: U25.8 (PC0), U29.3 (STAT1)
/~ESP_EN: R17.1, U25.33 (PB12)
/~RST: C30.1, R1.1, SW2.1, TP3.1, U25.7 (NRST)
/~STAT2: U25.16 (PA2), U29.4 (STAT2)
GND: C1.1, C2.1, C3.1, C4.1, C5.1, C6.1, C7.1, C8.1, C9.1, C10.1, C11.1, C12.1, C13.1, C14.1, C15.1, C16.1, C17.1, C18.1, C19.1, C20.1, C21.1, C22.1, C23.1, C24.1, C26.2, C27.1, C28.1, C29.1, C30.2, C31.2, C32.2, C33.1, C34.2, C35.2, C36.2, C37.1, C38.2, C39.1, C40.2, C41.1, C42.1, C43.1, C44.2, C45.2, C46.2, C47.2, C48.1, C50.2, C51.2, C52.2, C53.2, C54.1, C55.2, C56.1, H3.1, J1.A1 (GND), J1.A12 (GND), J1.B1 (GND), J1.B12 (GND), Q19.2 (S), Q21.1, R2.1, R3.1, R4.2, R5.1, R7.1, R9.2, R11.2, R18.2, R19.2, R20.1, R21.2, R24.1, SW2.2, TP6.1, U2.8 (GND), U3.8 (GND), U4.8 (GND), U5.8 (GND), U6.8 (GND), U7.8 (GND), U8.8 (GND), U8.13 (~OE), U10.8 (GND), U11.8 (GND), U12.8 (GND), U13.8 (GND), U14.8 (GND), U15.8 (GND), U17.8 (GND), U18.8 (GND), U19.8 (GND), U20.8 (GND), U21.8 (GND), U22.8 (GND), U23.8 (GND), U23.13 (~OE), U24.49 (GND), U25.12 (VSSA), U25.18 (VSS), U25.31 (VSS), U25.47 (VSS), U25.63 (VSS), U26.2 (VN), U27.3 (PGND), U27.9 (GND), U27.11 (PGND), U28.1 (GND), U29.2 (GND), U29.5 (GND), U29.7 (GND), U29.11 (GND), U31.B2 (VSS), U31.C1 (VSS), Y1.2, Y1.4
unnamed: AE1.1 (A), C25.1, C26.1
unnamed: C25.2, C27.2, U24.2 (LNA_IN)
unnamed: C31.1, U25.30 (VCAP_1)
unnamed: C37.2, J1.S1 (SHIELD), R3.2
unnamed: C38.1, FB1.2, J1.A4 (VBUS), J1.A9 (VBUS), J1.B4 (VBUS), J1.B9 (VBUS)
unnamed: C45.1, Q17.1 (G), Q18.1 (G), R10.1, R17.2
unnamed: C49.1, Q21.3, TP2.1, U30.6 (VSS)
unnamed: C49.2, R22.2, U30.5 (VDD)
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

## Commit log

2021-11-28 Finish anode driver 1-8 layout
    [rgb-led-nametag-48x16.kicad_pcb]
2021-11-28 Add driver bypassing
    [rgb-led-nametag-48x16.kicad_pcb]
2021-12-06 Finish STM32 digital interface assignment
    [esp32.sch, high-side-driver.sch, low-side-driver.sch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]
2021-12-08 Add multiplexing MCU and USB
    [high-side-driver.sch, low-side-driver.sch, rgb-led-nametag-48x16.kicad_pcb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]
2021-12-08 Add tag connect programming/debug interface
    [panel.sch, rgb-led-nametag-48x16.kicad_pcb, rgb-led-nametag-48x16.sch]
2021-12-10 Add mounting pad for safety pin
    [high-side-driver.sch, low-side-driver.sch, panel.sch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]
2021-12-10 Make space for STM32
    [low-side-driver.sch, panel.sch, rgb-led-nametag-48x16.kicad_pcb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]
2021-12-11 Route ESP32 SPI bus
    [esp32.sch, low-side-driver.sch, panel.sch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]
2021-12-11 Add preliminary ESP32 power layout
    [esp32.sch, low-side-driver.sch, panel.sch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]
2021-12-11 Layout horizontal busses
    [esp32.sch, high-side-driver.sch, low-side-driver.sch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]
2021-12-11 Layout 3V3 buck/boost converter
    [panel.sch, rgb-led-nametag-48x16.kicad_pcb, rgb-led-nametag-48x16.sch]
2021-12-11 Implement power path
    [esp32.sch, high-side-driver.sch, low-side-driver.sch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]
2021-12-11 Connect SWD to USB type C SBU
    [rgb-led-nametag-48x16.kicad_pcb, rgb-led-nametag-48x16.sch]
2021-12-11 Wire column mux SPI
    [rgb-led-nametag-48x16.kicad_pcb, rgb-led-nametag-48x16.sch]
2021-12-11 Layout remaining busses
    [esp32.sch, high-side-driver.sch, low-side-driver.sch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]
2021-12-11 Add primary battery protection
    [low-side-driver.sch, rgb-led-nametag-48x16.kicad_pcb, rgb-led-nametag-48x16.sch]
2021-12-11 Finish layout
    [high-side-driver.sch, low-side-driver.sch, panel.sch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]
2021-12-11 Connect charger state outputs to STM32
    [rgb-led-nametag-48x16.kicad_pcb, rgb-led-nametag-48x16.sch]
2021-12-11 Add pin1 markers
    [rgb-led-nametag-48x16.kicad_pcb]
2021-12-11 Fix DRC errors
    [rgb-led-nametag-48x16.kicad_pcb]
2021-12-11 Fix missaligned SWD testpoints
    [rgb-led-nametag-48x16.kicad_pcb]
2021-12-11 Add silkscreen markings
    [rgb-led-nametag-48x16.kicad_pcb]
2021-12-12 Use better ESP32 Pico D4 footprint
    [esp32.sch, high-side-driver.sch, low-side-driver.sch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]
2021-12-12 Hide U24 silkscreen designator again
    [rgb-led-nametag-48x16.kicad_pcb]
2021-12-12 Fix mounting type of SMT components
2021-12-12 Add 3d models
    [rgb-led-nametag-48x16.kicad_pcb]
2021-12-12 Add 3d model to VBUS enable inverter
    [rgb-led-nametag-48x16.kicad_pcb]
2021-12-13 Add DCDC inductor 3D model
    [rgb-led-nametag-48x16.kicad_pcb]
2021-12-14 Add a nicer safety pin 3D model
    [rgb-led-nametag-48x16.kicad_pcb]
2021-12-17 Improve layout
    [rgb-led-nametag-48x16.kicad_pcb]
2021-12-17 More layout improvements
    [rgb-led-nametag-48x16.kicad_pcb]
2021-12-17 Stitch L1 GND together on L2
    [rgb-led-nametag-48x16.kicad_pcb]
2021-12-17 Patch up L1 GND even more
    [rgb-led-nametag-48x16.kicad_pcb]
2021-12-17 Improve VBUS connectivity
    [rgb-led-nametag-48x16.kicad_pcb]
2021-12-17 Add more GND via stitching
    [rgb-led-nametag-48x16.kicad_pcb]
2021-12-17 Improve ESP32 3V3 power routing
    [rgb-led-nametag-48x16.kicad_pcb]
2021-12-18 Improve VBUS impedance to high side drivers
    [rgb-led-nametag-48x16.kicad_pcb]
2021-12-18 Add additional VBUS bulk capacitance
    [high-side-driver.sch, low-side-driver.sch, rgb-led-nametag-48x16.kicad_pcb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]
2021-12-20 Give Alps SKRK switch 3D model natural colors
2021-12-20 Add fuel gauge
    [low-side-driver.sch, panel.sch, rgb-led-nametag-48x16.kicad_pcb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]
2021-12-20 Improve BATT+ connectivity on main DC/DC
    [rgb-led-nametag-48x16.kicad_pcb]
2021-12-23 Align DC/DC pin 1 indicator
    [rgb-led-nametag-48x16.kicad_pcb]
2021-12-27 Fix 5.1k resistor package
    [rgb-led-nametag-48x16.sch]
2021-12-27 Connect ESD diode after SWD SBU resistors
    [rgb-led-nametag-48x16.sch]
2021-12-27 Fix row/column misnomer
    The row/column terms were swapped. The high side drivers control columns
    while the low side drivers switch the rows.
    [rgb-led-nametag-48x16.sch]
2021-12-27 Implement USB type C SWDIO SBU changes
    [rgb-led-nametag-48x16.kicad_pcb]
2021-12-30 Add 16MHz crystal
    Turns out the STM32F7 DFU bootloader uses the HSE for USB clocking and
    thus requires a crystal. No fallback to HSI is implemented. *sigh*
    [panel.sch, rgb-led-nametag-48x16.kicad_pcb, rgb-led-nametag-48x16.sch]
2021-12-30 Improce +3V3 routing for less wiggles
    [rgb-led-nametag-48x16.kicad_pcb]
2021-12-30 Right align year of design with my surname
    [rgb-led-nametag-48x16.kicad_pcb]
2021-12-30 Remove stray piece of trace on main DC/DC
    [rgb-led-nametag-48x16.kicad_pcb]
2021-12-30 Add solder paste definition to led panel contact pads
2021-12-30 Use new led panel footprint
    [rgb-led-nametag-48x16.kicad_pcb]
2021-12-31 Add missing part references
    [low-side-driver.sch, panel.sch, rgb-led-nametag-48x16.sch]
2022-01-15 Clean up schematic
    [esp32.kicad_sch, high-side-driver.kicad_sch, low-side-driver.kicad_sch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]
2022-01-15 Add schematic export
2022-01-15 Add note on assembly
2022-01-15 Update schematic to include title block
2022-03-18 Add simple 3d printable case
    [led-nametag-case.scad, led-nametag-case.stl]
2023-04-07 Add high fidelity led panel 3d model
    [rgb-led-nametag-48x16.kicad_pcb]
